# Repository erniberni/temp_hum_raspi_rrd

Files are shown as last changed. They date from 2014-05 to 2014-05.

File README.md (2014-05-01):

temp_hum_raspi_rrd
==================

Summary: Everything you need to build a 868 MHz wireless sensor network with collecting data in rrd databases and presenting graphical results. 
Please visit my blog http://glaskugelsehen.wordpress.com/  to get details and photos of the project.

1. A sensor based on TinyTX (http://nathan.chantrell.net/tinytx-wireless-sensor/) sends data on 868 MHz with RFM12B. The sensor in use is a DHT22 and the processor is a ATTiny84. The software of Nathan Chantrell's TinyTX was modified slightly to send also informations on uptime. For more information on the TinyTX visit the above mentioned webpage.

2. A board similar to the RFM12Pi board of OpenEnergyMonitor (http://wiki.openenergymonitor.org/index.php?title=RFM12Pi_V2) but with a Arduino mini instead of the ATMega chip. This leaves all other pins of the mini still available.  

3. RRD database on the Raspberry Pi was installed and the temperature, humidity and batterie voltage of the sensor is filled in

4. Graphical presentation off rrd data
The live data and historical data is presented with a apache/php webserver running on the RaspberryPi. The graphics are dynamically generated to prevent too many write cycles to sd flash.

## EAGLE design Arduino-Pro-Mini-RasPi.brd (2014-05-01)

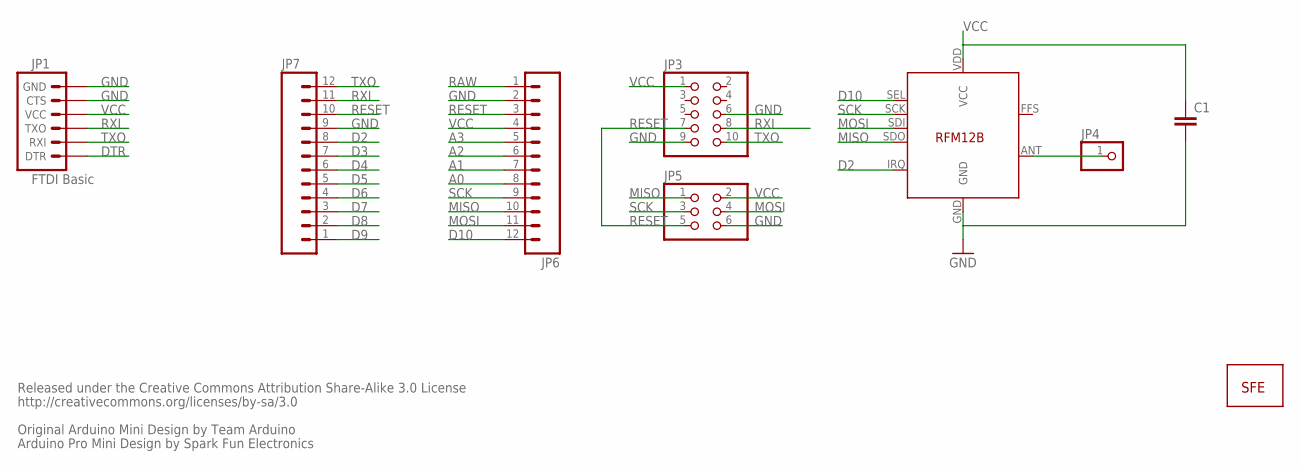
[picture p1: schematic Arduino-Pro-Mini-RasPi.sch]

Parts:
C1: C-EUC0805K; C0805K
JP1: FTDI Basic; 1X06
JP3: PINHD-2X5; 2X05
JP4: PINHD-1X1; 1X01
JP5: PINHD-2X3_2.54-SMD; 2X03SMD
JP6, JP7: M12PTH; 1X12
U$3: RFM12B
U$11: LOGO-SFENEW; SFE-NEW-WEBLOGO

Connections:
A0: JP6.8
A1: JP6.7
A2: JP6.6
A3: JP6.5
D2: JP7.8, U$3.IRQ
D3: JP7.7
D4: JP7.6
D5: JP7.5
D6: JP7.4
D7: JP7.3
D8: JP7.2
D9: JP7.1
D10: JP6.12, U$3.SEL
DTR: JP1.1 (DTR)
GND: C1.2, JP1.5 (CTS), JP1.6 (GND), JP3.6, JP3.9, JP5.6, JP6.2, JP7.9, U$3.GND
MISO: JP5.1, JP6.10, U$3.SDO
MOSI: JP5.4, JP6.11, U$3.SDI
unnamed: JP4.1, U$3.ANT
RAW: JP6.1
RESET: JP3.7, JP5.5, JP6.3, JP7.10
RXI: JP1.3 (TXO), JP3.8, JP7.11
SCK: JP5.3, JP6.9, U$3.SCK
TXO: JP1.2 (RXI), JP3.10, JP7.12
VCC: C1.1, JP1.4 (VCC), JP3.1, JP5.2, JP6.4, U$3.VDD (VCC)

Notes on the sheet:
Released under the Creative Commons Attribution Share-Alike 3.0 License
http://creativecommons.org/licenses/by-sa/3.0
Original Arduino Mini Design by Team Arduino
Arduino Pro Mini Design by Spark Fun Electronics

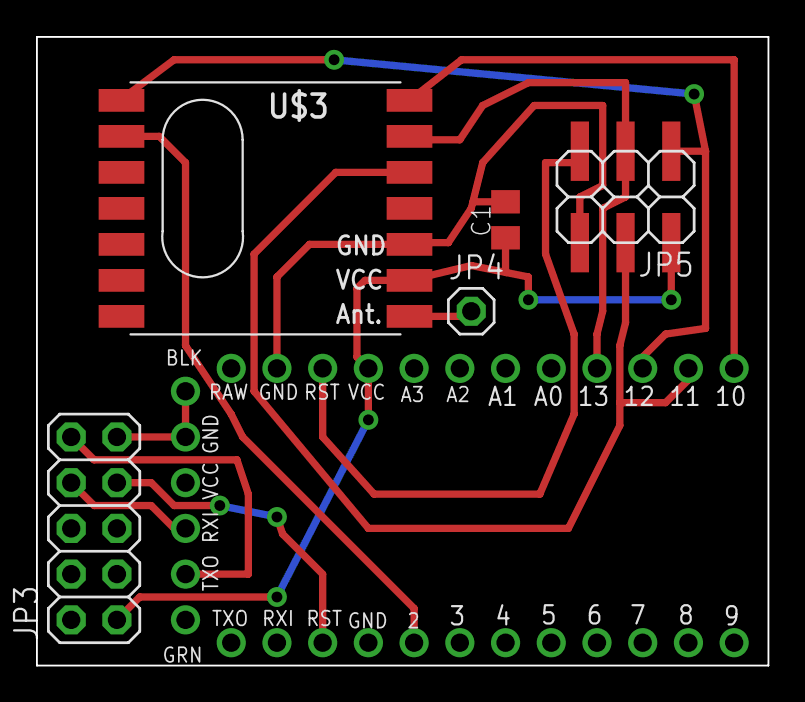
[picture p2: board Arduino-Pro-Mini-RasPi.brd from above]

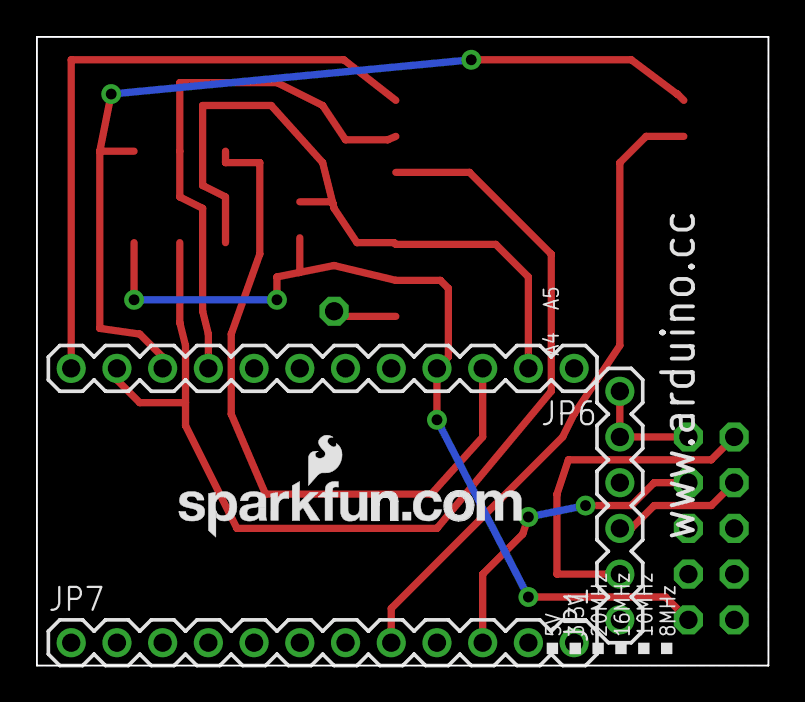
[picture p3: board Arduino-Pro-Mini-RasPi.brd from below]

Board: 2 copper layers, 40.6 x 34.9 mm, 9 parts (4 on the bottom side), 11 nets.

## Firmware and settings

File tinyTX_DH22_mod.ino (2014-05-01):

//----------------------------------------------------------------------------------------------------------------------
// This program is based on:
// TinyTX - An ATtiny84 and RFM12B Wireless Temperature & Humidity Sensor Node
// By Nathan Chantrell. For hardware design see http://nathan.chantrell.net/tinytx
//
// Using the DHT22 temperature and humidity sensor
//
// Licenced under the Creative Commons Attribution-ShareAlike 3.0 Unported (CC BY-SA 3.0) licence:
// http://creativecommons.org/licenses/by-sa/3.0/
//
// Requires Arduino IDE with arduino-tiny core: http://code.google.com/p/arduino-tiny/
//----------------------------------------------------------------------------------------------------------------------

// ATTiny84 operated @8MHz - Fuses: lfuse, hfuse, efuse: E2, D7, FF
// New feature: send information on uptime (minutes since boot) by Reinhard Nickels

#include <DHT22.h> // https://github.com/nathanchantrell/Arduino-DHT22
#include <JeeLib.h> // https://github.com/jcw/jeelib

ISR(WDT_vect) { Sleepy::watchdogEvent(); } // interrupt handler for JeeLabs Sleepy power saving

#define myNodeID 16      // RF12 node ID in the range 1-30
#define network 210      // RF12 Network group
#define freq RF12_868MHZ // Frequency of RFM12B module

#define USE_ACK           // Enable ACKs, comment out to disable
#define RETRY_PERIOD 3    // How soon to retry (in seconds) if ACK didn't come in
#define RETRY_LIMIT 5     // Maximum number of times to retry
#define ACK_TIME 50       // Number of milliseconds to wait for an ack  -> made this longer !

#define DHT22_PIN 10     // DHT sensor is connected on D10/ATtiny pin 10
#define DHT22_POWER 9 // DHT Power pin is connected on D9/ATtiny pin 9

DHT22 myDHT22(DHT22_PIN); // Setup the DHT

//########################################################################################################################
//Data Structure to be sent
//########################################################################################################################

 typedef struct {
     	  int humidity;	// Humidity reading
  	  int supplyV;	// Supply voltage
   	  int temp;	// Temperature reading
          unsigned long boots;    // minutes since boot, overflow after 49 days
 } Payload;

 Payload tinytx;

// Wait a few milliseconds for proper ACK
 #ifdef USE_ACK
  static byte waitForAck() {
   MilliTimer ackTimer;
   while (!ackTimer.poll(ACK_TIME)) {
     if (rf12_recvDone() && rf12_crc == 0 &&
        rf12_hdr == (RF12_HDR_DST | RF12_HDR_CTL | myNodeID))
        return 1;
     }
   return 0;
  }
 #endif

//--------------------------------------------------------------------------------------------------
// Send payload data via RF
//-------------------------------------------------------------------------------------------------
 static void rfwrite(){
  #ifdef USE_ACK
   for (byte i = 0; i <= RETRY_LIMIT; ++i) {  // tx and wait for ack up to RETRY_LIMIT times
     rf12_sleep(-1);              // Wake up RF module
      while (!rf12_canSend())
      rf12_recvDone();
      rf12_sendStart(RF12_HDR_ACK, &tinytx, sizeof tinytx); 
      rf12_sendWait(2);           // Wait for RF to finish sending while in standby mode
      byte acked = waitForAck();  // Wait for ACK
      rf12_sleep(0);              // Put RF module to sleep
      if (acked) { return; }      // Return if ACK received
  
   Sleepy::loseSomeTime(RETRY_PERIOD * 1000);     // If no ack received wait and try again
   }
  #else
     rf12_sleep(-1);              // Wake up RF module
     while (!rf12_canSend())
     rf12_recvDone();
     rf12_sendStart(0, &tinytx, sizeof tinytx); 
     rf12_sendWait(2);           // Wait for RF to finish sending while in standby mode
     rf12_sleep(0);              // Put RF module to sleep
     return;
  #endif
 }



//--------------------------------------------------------------------------------------------------
// Read current supply voltage
//--------------------------------------------------------------------------------------------------
 long readVcc() {
   bitClear(PRR, PRADC); ADCSRA |= bit(ADEN); // Enable the ADC
   long result;
   // Read 1.1V reference against Vcc
   #if defined(__AVR_ATtiny84__) 
    ADMUX = _BV(MUX5) | _BV(MUX0); // For ATtiny84
   #else
    ADMUX = _BV(REFS0) | _BV(MUX3) | _BV(MUX2) | _BV(MUX1);  // For ATmega328
   #endif 
   delay(2); // Wait for Vref to settle
   ADCSRA |= _BV(ADSC); // Convert
   while (bit_is_set(ADCSRA,ADSC));
   result = ADCL;
   result |= ADCH<<8;
   result = 1126400L / result; // Back-calculate Vcc in mV
   ADCSRA &= ~ bit(ADEN); bitSet(PRR, PRADC); // Disable the ADC to save power
   return result;
} 

//########################################################################################################################

void setup() {

  rf12_initialize(myNodeID,freq,network); // Initialize RFM12 with settings defined above 
  rf12_sleep(0);                          // Put the RFM12 to sleep

  pinMode(DHT22_POWER, OUTPUT); // set power pin for DHT to output
  
  PRR = bit(PRTIM1); // only keep timer 0 going
  
  ADCSRA &= ~ bit(ADEN); bitSet(PRR, PRADC); // Disable the ADC to save power
  
}

void loop() {
  
  digitalWrite(DHT22_POWER, HIGH); // turn DHT sensor on

  DHT22_ERROR_t errorCode;
  
  Sleepy::loseSomeTime(2000); // Sensor requires minimum 2s warm-up after power-on.
  
  errorCode = myDHT22.readData(); // read data from sensor

  if (errorCode == DHT_ERROR_NONE) { // data is good

    tinytx.temp = (myDHT22.getTemperatureC()*100); // Get temperature reading and convert to integer, reversed at receiving end
    
    tinytx.humidity = (myDHT22.getHumidity()*100); // Get humidity reading and convert to integer, reversed at receiving end

    tinytx.supplyV = readVcc(); // Get supply voltage
    tinytx.boots = millis()/1000/60;

    rfwrite(); // Send data via RF 

  }

  digitalWrite(DHT22_POWER, LOW); // turn DS18B20 off
  
  Sleepy::loseSomeTime(54000); //JeeLabs power save function: enter low power mode for 60 seconds (valid range 16-65000 ms)
  // 60.000 = 76s 
}

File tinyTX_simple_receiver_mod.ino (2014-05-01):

//----------------------------------------------------------------------------------------------------------------------
// This program is based on:
// TinyTX Simple Receive Example
// By Nathan Chantrell. 
//
// Licenced under the Creative Commons Attribution-ShareAlike 3.0 Unported (CC BY-SA 3.0) licence:
// http://creativecommons.org/licenses/by-sa/3.0/
//----------------------------------------------------------------------------------------------------------------------
// Output to serial interface was redesigned by Reinhard Nickels

#include <JeeLib.h> // https://github.com/jcw/jeelib

// Fixed RF12 settings
#define MYNODE 30            //node ID of the receiever
#define freq RF12_868MHZ     //frequency
#define group 210            //network group

typedef struct {
  int humidity;	// Humidity reading
  int supplyV;	// Supply voltage
  int temp;	// Temperature reading
  unsigned long boots;   // minutes since boot, nach 49 Tagen Überlauf
} 
Payload;
Payload rx;

int nodeID;    //node ID of tx, extracted from RF datapacket. Not transmitted as part of structure
unsigned long last_s;

void setup () {
  Serial.begin(115200);
  rf12_initialize(MYNODE, freq,group); // Initialise the RFM12B
//  Serial.println("TinyTX Simple Receive Example");
//  Serial.println("-----------------------------");
  Serial.println("Waiting for data");
}

void loop() {
  if (rf12_recvDone() && rf12_crc == 0 && (rf12_hdr & RF12_HDR_CTL) == 0) {
    nodeID = rf12_hdr & 0x1F;  // get node ID
    rx = *(Payload*) rf12_data;
    int humidity = rx.humidity;
    int supplyV = rx.supplyV;
    int temp = rx.temp;
    unsigned long btime = rx.boots;
    if (RF12_WANTS_ACK) {                  // Send ACK if requested
      rf12_sendStart(RF12_ACK_REPLY, 0, 0);
//      Serial.print("ack\t");
    }
    Serial.print(nodeID);
    Serial.print("\t");
    Serial.print(supplyV);
    Serial.print("\t");
    Serial.print(temp);
    Serial.print("\t");
    Serial.print(humidity);
    Serial.print("\t");
    Serial.print(btime);
    Serial.print("\t");
    unsigned long rectime = millis()/1000;
    Serial.print(rectime);
    Serial.print("\t");
    Serial.println(rectime -last_s); 
    last_s = millis()/1000;
  }
}
